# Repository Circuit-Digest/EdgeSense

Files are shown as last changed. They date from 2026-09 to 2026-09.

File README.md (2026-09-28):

# EdgeSense: STM32 Edge AI Texture and Gesture Classifier

```
  ███████╗██████╗  ██████╗ ███████╗███████╗███████╗███╗   ██╗███████╗███████╗
  ██╔════╝██╔══██╗██╔════╝ ██╔════╝██╔════╝██╔════╝████╗  ██║██╔════╝██╔════╝
  █████╗  ██║  ██║██║  ███╗█████╗  ███████╗█████╗  ██╔██╗ ██║███████╗█████╗  
  ██╔══╝  ██║  ██║██║   ██║██╔══╝  ╚════██║██╔══╝  ██║╚██╗██║╚════██║██╔══╝  
  ███████╗██████╔╝╚██████╔╝███████╗███████║███████╗██║ ╚████║███████║███████╗
  ╚══════╝╚═════╝  ╚═════╝ ╚══════╝╚══════╝╚══════╝╚═╝  ╚═══╝╚══════╝╚══════╝
```







**EdgeSense** is a compact, high-performance edge artificial intelligence platform that performs on-device 3D gesture recognition, surface/texture classification, static hand posture detection, and optical obscuration sensing. 

Powered by the **STM32H533CEU6** (ARM Cortex-M33 running at 250 MHz) and the **ST VL53L8CH** 8x8 direct Time-of-Flight (dToF) sensor, EdgeSense executes quantized neural networks entirely on-chip in real time with sub-7 ms inference latency.

---

## Key Capabilities

EdgeSense features a runtime multi-model execution engine (`pipeline_manager.c`) allowing dynamic model switching over USB CDC:

1. **3D Gesture Recognition (8x8 ToF, 15 FPS)**:
   - Recognizes dynamic directional swipes: `SWIPE_LEFT`, `SWIPE_RIGHT`, `SWIPE_UP`, `SWIPE_DOWN`, and `IDLE`.
   - Continuous 15-frame sliding window (1.0 s temporal context) with zero gesture-lockout.
   - Physical temporal motion energy guard to eliminate stationary phantom triggers.
   - Inference latency: **~6.8 ms** per inference.

2. **Distance-Invariant Surface Classifier (4x4 CNH, 48 Bins)**:
   - Classifies textures and materials: `HARD_FLOOR` (tile/wood), `CARPET` (subsurface scattering), `SPECULAR` (mirrors/polished metal), and `VOID` (drop-offs/cliffs).
   - Utilizes ST-aligned Cumulative Normalized Histogram (CNH) peak-centered canonical alignment.
   - Inference latency: **~3.2 ms** per inference.

3. **Static Hand Posture Classifier (8x8 Depth + Signal Intensity)**:
   - Identifies static human hand postures: `FLAT_HAND`, `LIKE`, `DISLIKE`, `BREAK_TIME`, `FIST`, and `NONE`.
   - Dual-channel 2D-CNN processing distance geometry and photon reflection intensity simultaneously.
   - Robust to ambient lighting variations and skin tone differences.
   - Inference latency: **~4.1 ms** per inference.

4. **Optical Obscuration & Smoke Detector**:
   - Detects microscopic particles, airborne obscuration, and smoke.
   - Computes multi-zone signal attenuation and ambient light scattering indices in real time.

---

## Hardware Specifications

| Component | Specification |
|---|---|
| **Microcontroller** | STMicroelectronics STM32H533CEUx (ARM Cortex-M33, 250 MHz, TrustZone, FPU, DSP) |
| **On-Chip Memory** | 512 KB Flash ROM, 256 KB SRAM |
| **ToF Sensor** | STMicroelectronics VL53L8CH / VL53LMZ Direct Time-of-Flight |
| **Sensor FoV** | 65° Diagonal Field of View |
| **Spatial Resolution** | 8x8 (64 zones) or 4x4 (16 zones with 48-bin CNH histograms) |
| **Ranging Distance** | 20 mm to 4000 mm |
| **Host Connectivity** | High-Speed USB 2.0 CDC (Virtual COM Port @ 921600 baud) |
| **Communication Bus** | Dedicated Fast-mode Plus (Fm+) 1 MHz I2C bus |
| **Power Supply** | 5V via USB-C or 3.3V external rail |

---

## Repository Structure

```
EdgeSense/
├── Core/                      # STM32H533 HAL drivers, ISRs, and main loop
├── Drivers/                   # CMSIS and STM32H5xx HAL libraries
├── Middlewares/               # ST X-CUBE-AI runtime v10.2.1 & USB Device stack
├── USB_Device/                # USB CDC Virtual COM Port descriptors & handlers
├── VL53LMZ_ULD/               # Ultra-Lite Driver & CNH Histogram Plugin
├── X-CUBE-AI/                 # Edge AI Pipeline Manager & Active Networks
│   └── App/                   # pipeline_manager, model_gesture, model_posture, model_surface, model_smoke
│
├── Models/                    # Pre-trained production ONNX models & datasets
│   ├── gesture_nn_model.onnx  # 5-class 2D-CNN Gesture Classifier
│   ├── posture_nn_model.onnx  # 6-class 2D-CNN Posture Classifier
│   ├── surface_nn_model.onnx  # 4-class 1D-CNN Surface Classifier
│   ├── gesture_dataset.npz    # Default Gesture training dataset
│   ├── posture_dataset.npz    # Default Posture training dataset
│   ├── surface_dataset.npz    # Default Surface training dataset
│   └── Archive/               # Intermediate training iterations
│
├── Tools/                     # Python Studio, GUIs, and deploy automation
│   ├── Studio/                # 4-in-1 EdgeSense Neural Network Studio
│   │   ├── edgesense_nn_studio.py
│   │   ├── run_nn_studio.bat
│   │   ├── deploy_model_to_mcu.bat
│   │   ├── deploy_posture_model_to_mcu.bat
│   │   ├── deploy_surface_model_to_mcu.bat
│   │   ├── requirements.txt
│   │   └── screenshots/
│   ├── Visualizer/            # Real-time multi-zone depth viewer
│   ├── Flashing/              # STM32CubeProgrammer CLI flasher
│   └── Tests/                 # Automated AT pipeline verification tests
│
├── Hardware/                  # KiCad EDA design files, schematics & BOM
│   ├── Schematics/            # KiCad project, schematics, PCB layout
│   └── Production/            # Gerber ZIP, Pick-and-Place, BOM
│
├── Docs/                      # Technical references & protocol manuals
│   ├── Architecture.md        # System architecture and memory specs
│   └── AT_Command_Manual.md   # Complete AT command serial reference
│
├── EdgeSense.ioc              # STM32CubeMX hardware pinout and clock config
├── STM32H533CEUX_FLASH.ld     # Flash linker script
├── LICENSE                    # GNU General Public License v3.0
└── README.md                  # This documentation
```

---

## Getting Started

### 1. Prerequisites
- **STM32CubeIDE** (v2.2.0 or newer) with GNU Tools for STM32 (ARM GCC 14.3+)
- **ST Edge AI Core (X-CUBE-AI)** v10.2.1+
- **Python** 3.10+ (64-bit)
- **ST-LINK V2 / V3** Programmer

### 2. Python Environment Setup
Install the required dependencies for the EdgeSense AI Studio:
```bash
cd Tools/Studio
pip install -r requirements.txt
```

### 3. Launching EdgeSense Studio
Double-click `Tools/Studio/run_nn_studio.bat` or run:
```bash
python Tools/Studio/edgesense_nn_studio.py
```
From the Studio, you can:
- View live 8x8 depth heatmaps and 4x4 CNH pulse shapes.
- Record new training datasets for Gestures, Postures, or Surfaces.
- Train PyTorch neural networks with 1 click.
- Deploy trained models to the STM32H533 via `deploy_*_model_to_mcu.bat` automatically.

### 4. Building Firmware via Command Line
```bash
make -C Debug all
```
The compiled binary will be located at `Debug/EdgeSense.elf` and `Debug/EdgeSense.bin`.

### 5. Flashing Firmware
Connect your ST-LINK to the SWD header and run:
```bash
Tools/Flashing/flash_firmware.bat
```

---

## Serial Communication & AT Commands

Connect to the USB CDC COM port at **921600 baud, 8-N-1**.

| Command | Action |
|---|---|
| `AT` | Verify connection (returns `OK`) |
| `AT+MODE=?` | List available modes: `(0:GESTURE, 1:SURFACE, 2:POSTURE, 3:SMOKE)` |
| `AT+MODE?` | Query currently active mode |
| `AT+MODE=0` | Switch to 3D Gesture Recognition mode |
| `AT+MODE=1` | Switch to Surface / Texture Classifier mode |
| `AT+MODE=2` | Switch to Hand Posture Classifier mode |
| `AT+MODE=3` | Switch to Optical Smoke / Obscuration mode |
| `AT+STREAM=1` | Enable real-time 8x8 JSON depth streaming |
| `AT+STREAM=0` | Disable streaming |
| `AT+STATUS` | View sensor health, frame counts, and FPS |
| `AT+RESET` | Software system reboot |

---

## License

This project is licensed under the **GNU General Public License v3.0**. See the [LICENSE](LICENSE) file for details.

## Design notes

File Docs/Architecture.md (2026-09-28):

# EdgeSense System Architecture & Hardware Specification

/*
 * Architecture.md
 * System pipeline architecture and technical documentation for EdgeSense
 *
 * Copyright (c) 2026 Dharagesh and Circuit Digest
 * https://github.com/Circuit-Digest/EdgeSense
 * Licensed under GNU General Public License v3.0
 */

`
  ███████╗██████╗  ██████╗ ███████╗███████╗███████╗███╗   ██╗███████╗███████╗
  ██╔════╝██╔══██╗██╔════╝ ██╔════╝██╔════╝██╔════╝████╗  ██║██╔════╝██╔════╝
  █████╗  ██║  ██║██║  ███╗█████╗  ███████╗█████╗  ██╔██╗ ██║███████╗█████╗  
  ██╔══╝  ██║  ██║██║   ██║██╔══╝  ╚════██║██╔══╝  ██║╚██╗██║╚════██║██╔══╝  
  ███████╗██████╔╝╚██████╔╝███████╗███████║███████╗██║ ╚████║███████║███████╗
  ╚══════╝╚═════╝  ╚═════╝ ╚══════╝╚══════╝╚══════╝╚═╝  ╚═══╝╚══════╝╚══════╝
`

---

## 1. Hardware Architecture

EdgeSense is an ultra-compact edge AI sensing node combining:
- **MCU**: STMicroelectronics **STM32H533CEUx**
  - ARM Cortex-M33 with TrustZone, FPU (single-precision), DSP instructions
  - 250 MHz core clock, 512 KB Flash, 256 KB SRAM
  - High-Speed USB 2.0 (FS Device PHY)
  - Dedicated I3C / Fast-mode Plus (Fm+) 1 MHz I2C bus
- **Sensor**: STMicroelectronics **VL53L8CH / VL53LMZ** Direct Time-of-Flight (dToF)
  - 8x8 multizone ranging (64 independent distance zones)
  - 4x4 Cumulative Normalized Histogram (CNH) binning mode (48 physical bins per zone)
  - 940 nm VCSEL emitter with integrated metasurface lens
  - Wide 65° diagonal Field of View (FoV)

---

## 2. Firmware Execution Pipeline

EdgeSense runs an interrupt-driven, bare-metal cooperative architecture designed for low latency and zero heap fragmentation:

`mermaid
graph TD
    A[VL53LMZ Hardware INT Pin] -->|EXTI Fallback / Poll| B[Ranging Data Ready]
    B --> C[vl53lmz_get_ranging_data]
    C --> D{Active Pipeline Mode}
    D -->|MODE_GESTURE| E[model_gesture_process]
    D -->|MODE_SURFACE| F[model_surface_process]
    D -->|MODE_POSTURE| G[model_posture_process]
    D -->|MODE_SMOKE| H[model_smoke_process]
    E --> I[pipeline_manager_report_event]
    F --> I
    G --> I
    H --> I
    I -->|JSON / ASCII| J[USB CDC Virtual COM Port]
`

### Memory Footprint on STM32H533CEUx
- **Flash ROM**: ~230 KB (45% of 512 KB)
- **SRAM**: ~87 KB (34% of 256 KB)
- **Network Weights & Activations**:
  - gesture_nn: 18.5 KB weights, 15.0 KB activations buffer (reusable pool)
  - posture_nn: 12.2 KB weights, 8.4 KB activations buffer
  - surface_nn: 7.8 KB weights, 4.2 KB activations buffer

---

## 3. Dynamic Mode Switching Engine

The runtime switching engine (pipeline_manager.c) controls sensor configuration and active neural network instances without resetting the MCU:

1. Sensor ranging is safely stopped via 
l53lmz_stop_ranging().
2. Sensor resolution is re-indexed:
   - **Gesture / Posture / Smoke**: VL53LMZ_RESOLUTION_8X8 (64 zones, 15 Hz)
   - **Surface Classification**: VL53LMZ_RESOLUTION_4X4 with CNH histogram readout
3. The AI network pointer is dynamically swapped in the pipeline table.
4. Feature buffers are zeroed to prevent cross-mode bleed.
5. Ranging is restarted via 
l53lmz_start_ranging().

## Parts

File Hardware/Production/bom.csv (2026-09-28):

Designator | Footprint | Quantity | Value | LCSC Part #
C1, C20, C3, C4, C5, C6 | 0603 | 6 | 1uF
C12, C13, C14, C15, C16, C27, C28, C29, C30 | 0603 | 9 | 100nF
C17 | 0603 | 1 | 10uF
C18, C19 | 0603 | 2 | 2.2uF
C2 | 0603 | 1 | 10nF
C21, C22 | 0603 | 2 | 0.1uF
C23, C24 | 0603 | 2 | 18pF
C25, C26 | 0603 | 2 | 9pF
D1, D2 | 0603 | 2 | LED
IC1 | UFQFPN-48_STM | 1 | STM32H533CEU6
IC2 | VL53L8CHV0GC1 | 1 | VL53L8CHV0GC_1
J2 | JST_PH_B2B-PH-K_1x02_P2.00mm_Vertical | 1 | BAT
J3 | PinHeader_1x05_P2.54mm_Vertical | 1 | STLINK
J4 | USB_C_Receptacle_HCTL_HC-TYPE-C-16P-01A | 1 | USB_C_Receptacle_USB2.0_16P
J5 | PinHeader_1x04_P2.54mm_Vertical | 1 | UART
R1 | 0603 | 1 | 12K
R10, R14, R15, R16, R8, R9 | 0603 | 6 | 47K
R11, R6 | 0603 | 2 | 10K
R12, R13 | 0603 | 2 | 5K1
R17 | 0603 | 1 | 7K5
R2 | 0603 | 1 | 3K3
R3 | 0603 | 1 | 1K
R4 | 0603 | 1 | 470R
R5, R7 | 0603 | 2 | 220R
SW1, SW2 | SW_SPST_TS-1088-xR025 | 2 | SW_Push
U1 | DFN_SPU33R_STM | 1 | ST1L08SPU33R
U2 | VFQFPN-16_STM | 1 | L6924D013TR
U3 | SOT-223-3_TabPin2 | 1 | LD1117V18
U4 | TSSOP20_4P4X6P5_STM | 1 | ST2378ETTR
Y1 | Crystal_SMD_3215-2Pin_3.2x1.5mm | 1 | 32KHz
Y2 | Crystal_SMD_3225-4Pin_3.2x2.5mm | 1 | Crystal_GND24_Small

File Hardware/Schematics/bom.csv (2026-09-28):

Designator | Footprint | Quantity | Manufacturer part number | LCSC Part #
BAT | JST_PH_B2B-PH-K_1x02_P2.00mm_Vertical | 1 | BAT
C1, C20, C3, C4, C5, C6 | 603 | 6 | 1uF
C10, C12, C13, C14, C15, C16, C8, C9 | 603 | 8 | 100nF
C17, C23, C24 | 603 | 3 | 10uF
C18, C19 | 603 | 2 | 2.2uF
C2 | 603 | 1 | 10nF
C21, C22 | 603 | 2 | 0.1uF
C25, C26 | 603 | 2 | 9pF
D1, D2 | 603 | 2 | LED
IC1 | UFQFPN-48_STM | 1 | STM32H533CEU6
IC2 | VL53L8CHV0GC1 | 1 | VL53L8CHV0GC_1
J3 | PinHeader_1x05_P2.54mm_Vertical | 1 | STLINK
J4 | USB_C_Receptacle_HCTL_HC-TYPE-C-16P-01A | 1 | USB_C_Receptacle_USB2.0_16P
J5 | PinHeader_1x04_P2.54mm_Vertical | 1 | UART
R1 | 603 | 1 | 12K
R10, R14, R15, R16, R8, R9 | 603 | 6 | 47K
R11, R6 | 603 | 2 | 10K
R12, R13 | 603 | 2 | 5K1
R17_2 | 603 | 1 | 7K5
R17 | 603 | 1 | 7500R
R2 | 603 | 1 | 3K3
R3 | 603 | 1 | 1K
R4 | 603 | 1 | 470R
R5, R7 | 603 | 2 | 220R
SW1, SW2 | SW_SPST_TS-1088-xR025 | 2 | SW_Push
U1 | DFN_SPU33R_STM | 1 | ST1L08SPU33R
U2 | VFQFPN-16_STM | 1 | L6924D013TR
U3 | SOT-223-3_TabPin2 | 1 | LD1117V18
U4 | TSSOP20_4P4X6P5_STM | 1 | ST2378ETTR
Y1 | Crystal_SMD_3215-2Pin_3.2x1.5mm | 1 | 32KHz
Y2 | XTAL_ABM8-24.000MHZ-D2Y-T | 1 | 24MHz

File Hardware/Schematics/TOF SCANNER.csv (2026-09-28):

Id | Designator | Footprint | Quantity | Designation | Supplier and ref
1 | BAT | JST_PH_B2B-PH-K_1x02_P2.00mm_Vertical | 1 | BAT
2 | C1, C3, C4, C5, C6, C20 | C_0603_1608Metric | 6 | 1uF
3 | C2 | C_0603_1608Metric | 1 | 10nF
4 | C8, C9, C10, C12, C13, C14, C15, C16 | C_0603_1608Metric | 8 | 100nF
5 | C17, C23, C24 | C_0603_1608Metric | 3 | 10uF
6 | C18, C19 | C_0603_1608Metric | 2 | 2.2uF
7 | C21, C22 | C_0603_1608Metric | 2 | 0.1uF
8 | C25, C26 | C_0603_1608Metric | 2 | 9pF
9 | D1, D2 | LED_0603_1608Metric | 2 | LED
10 | IC1 | UFQFPN-48_STM | 1 | STM32H533CEU6
11 | IC2 | VL53L8CHV0GC1 | 1 | VL53L8CHV0GC_1
12 | J3 | PinHeader_1x05_P2.54mm_Vertical | 1 | STLINK
13 | J4 | USB_C_Receptacle_HCTL_HC-TYPE-C-16P-01A | 1 | USB_C_Receptacle_USB2.0_16P
14 | J5 | PinHeader_1x04_P2.54mm_Vertical | 1 | UART
15 | R1 | R_0603_1608Metric | 1 | 12K
16 | R2 | R_0603_1608Metric | 1 | 3K3
17 | R3 | R_0603_1608Metric | 1 | 1K
18 | R4 | R_0603_1608Metric | 1 | 470R
19 | R5, R7 | R_0603_1608Metric | 2 | 220R
20 | R6, R11 | R_0603_1608Metric | 2 | 10K
21 | R8, R9, R10, R14, R15, R16 | R_0603_1608Metric | 6 | 47K
22 | R12, R13 | R_0603_1608Metric | 2 | 5K1
23 | R17 | R_0603_1608Metric | 1 | 7K5
24 | R17 | R_0603_1608Metric | 1 | 7500R
25 | SW1, SW2 | SW_SPST_TS-1088-xR025 | 2 | SW_Push
26 | U1 | DFN_SPU33R_STM | 1 | ST1L08SPU33R
27 | U2 | VFQFPN-16_STM | 1 | L6924D013TR
28 | U3 | SOT-223-3_TabPin2 | 1 | LD1117V18
29 | U4 | TSSOP20_4P4X6P5_STM | 1 | ST2378ETTR
30 | Y1 | Crystal_SMD_3215-2Pin_3.2x1.5mm | 1 | 32KHz
31 | Y2 | XTAL_ABM8-24.000MHZ-D2Y-T | 1 | 24MHz

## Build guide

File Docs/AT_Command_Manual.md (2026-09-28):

# EdgeSense AT Command Interface Manual

/*
 * AT_Command_Manual.md
 * Serial Command Protocol and Pipeline Control Specification
 *
 * Copyright (c) 2026 Dharagesh and Circuit Digest
 * https://github.com/Circuit-Digest/EdgeSense
 * Licensed under GNU General Public License v3.0
 */

All commands are sent over the USB CDC Virtual COM port (921600 baud, 8-N-1) terminated with \r\n (CRLF).

---

## Command Reference

| Command | Parameter | Response | Description |
|---|---|---|---|
| `AT` | *None* | `OK` | Link verification / Ping |
| `AT+MODE=?` | *None* | `+MODE: (0:GESTURE, 1:SURFACE, 2:POSTURE, 3:SMOKE)` | List supported operating modes |
| `AT+MODE?` | *None* | `+MODE: <id>,<NAME>` | Query current operating mode |
| `AT+MODE=<id>` | `0` to `3` | `OK` or `ERROR: ...` | Switch active pipeline mode at runtime |
| `AT+STREAM=<en>` | `0` or `1` | `OK` | Enable (`1`) or disable (`0`) real-time JSON depth matrix streaming |
| `AT+STATUS` | *None* | Multi-line diagnostic dump | Get sensor health, frame count, temperature, and FPS |
| `AT+INFO` | *None* | Firmware metadata | Print version, MCU target, sensor UID, and build date |
| `AT+RESET` | *None* | `OK` | Perform software system reset via NVIC |

---

## Operating Modes

### Mode 0: 3D Gesture Recognition (`GESTURE`)
- **Resolution**: 8x8 zones (64 zones) @ 15 Hz
- **Architecture**: 2D-CNN with 15-frame sliding window (1.0 s temporal history)
- **Output Classes**: `IDLE`, `SWIPE_LEFT`, `SWIPE_RIGHT`, `SWIPE_UP`, `SWIPE_DOWN`
- **Output Event**:
  `[AI GESTURE] >>> DETECTED: SWIPE_LEFT (Confidence:  96.7% | Latency: 6805 us | 1633263 cycles) <<<`

### Mode 1: Surface / Texture Classifier (`SURFACE`)
- **Resolution**: 4x4 zones (16 zones) with 48-bin CNH histograms @ 15 Hz
- **Architecture**: 1D-CNN Canonical Peak-Centered Histogram Network
- **Output Classes**: `HARD_FLOOR`, `CARPET`, `SPECULAR`, `VOID`
- **Output Event**:
  `[AI SURFACE] >>> DETECTED: CARPET (Confidence:  98.2% | Latency: 3210 us) <<<`

### Mode 2: Static Hand Posture Classifier (`POSTURE`)
- **Resolution**: 8x8 zones (64 zones) @ 15 Hz
- **Architecture**: Dual-Channel 2D-CNN (Depth + Signal Intensity)
- **Output Classes**: `NONE`, `FLAT_HAND`, `LIKE`, `DISLIKE`, `BREAK_TIME`, `FIST`
- **Output Event**:
  `[AI POSTURE] >>> DETECTED: LIKE (Confidence:  97.5% | Latency: 4120 us) <<<`

### Mode 3: Optical Obscuration / Smoke Detector (`SMOKE`)
- **Resolution**: 8x8 zones (64 zones) @ 15 Hz
- **Methodology**: Multi-zone signal attenuation and ambient light scattering ratio
- **Output Event**:
  `[AI SMOKE] >>> ALERT: OBSCURATION_DETECTED (Level: 42% | Attenuation: -3.8 dB) <<<`

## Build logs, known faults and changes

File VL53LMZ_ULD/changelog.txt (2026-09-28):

********************************************************************************
*
* STMicroelectronics - VL53L7CH/VL53L8CH Ultra Lite Driver
*
********************************************************************************

# Driver version history 

---------------------------------------------------------------------------------------------------------------
Version : 2.0.16
Date: 24/06/2025
Comments :
- Add missing declarations for vl53lmz_get_ranging_frequency_x256() / vl53lmz_set_ranging_frequency_x256()
- Modified glare_filter get/set functions to not generate compiler warnings.
- Skipped version 2.0.15 due to confusion about update history.
---------------------------------------------------------------------------------------------------------------

---------------------------------------------------------------------------------------------------------------
Version : 2.0.14
Date: 14/11/2024
Comments :
- Fix compatibility with VL53L7.
- New API functions to allow more precise setting of ranging frequency:
  -- vl53lmz_get_ranging_frequency_x256() / vl53lmz_set_ranging_frequency_x256()
---------------------------------------------------------------------------------------------------------------

---------------------------------------------------------------------------------------------------------------
Version : 2.0.13
Date: 12/11/2024
Comments :
- Updates in vl53lmz_buffers.h file to align it with L8CX ULD v2.0.0 (updated spread spectrum settings)
- Enable download FW checksum feature.
- Added SPI example project. Aligned I2C and SPI projects.
- Added GPIO pin allocation PDF files in example projects.
---------------------------------------------------------------------------------------------------------------

---------------------------------------------------------------------------------------------------------------
Version : 2.0.11
Date: 12/03/2024
Comments :
- Changed method used to set module_type so that it correctly distinguishes between L5 and L7 parts.
- Modified vl53lmz_is_alive() to only store device_id and revision_id.
- Moved to MM FW v1.8 (modified field order in low_reflectance_filter_t)
---------------------------------------------------------------------------------------------------------------

---------------------------------------------------------------------------------------------------------------
Version : 2.0.10
Date: 07/12/2023
Comments :
- Fixed wrong conversion of Ambient and Histogram values in Example_12. Values were a factor of 2x too low.
- Fixed incorrect sizing of cnh_data_buffer_t.
- Fixed incorrect comparison for is_auto_stop_enabled.
- Added VL53LMZ_POWER_MODE_DEEP_SLEEP mode.
- Include MM FW v1.7 which contains:
.... Improved rad2perp for L8
.... Improved wrap-around check algo
.... Option to skip intr on first two frames of detection thresholds
.... Calculation of a FW checksum
.... Fix for incorrect operation with very negative values of CNH start_bin
.... Added first_bin to sci_persistent_data[2][31:16]
---------------------------------------------------------------------------------------------------------------

---------------------------------------------------------------------------------------------------------------
Version : 2.0.9
Date : 25/07/2023
Comments :
- Fixed issue in  vl53lmz_enable/disable_internal_cp functions which prevented use with VL53L7CH.
- Added module_type to VL53LMZ_Configuration to provide a public location to read the module type. This
field is set during calls to vl53lmz_is_alive() and vl53lmz_init().
---------------------------------------------------------------------------------------------------------------

---------------------------------------------------------------------------------------------------------------
Version : 2.0.8
Date : 16/06/2023
Comments : Initial driver release.
---------------------------------------------------------------------------------------------------------------

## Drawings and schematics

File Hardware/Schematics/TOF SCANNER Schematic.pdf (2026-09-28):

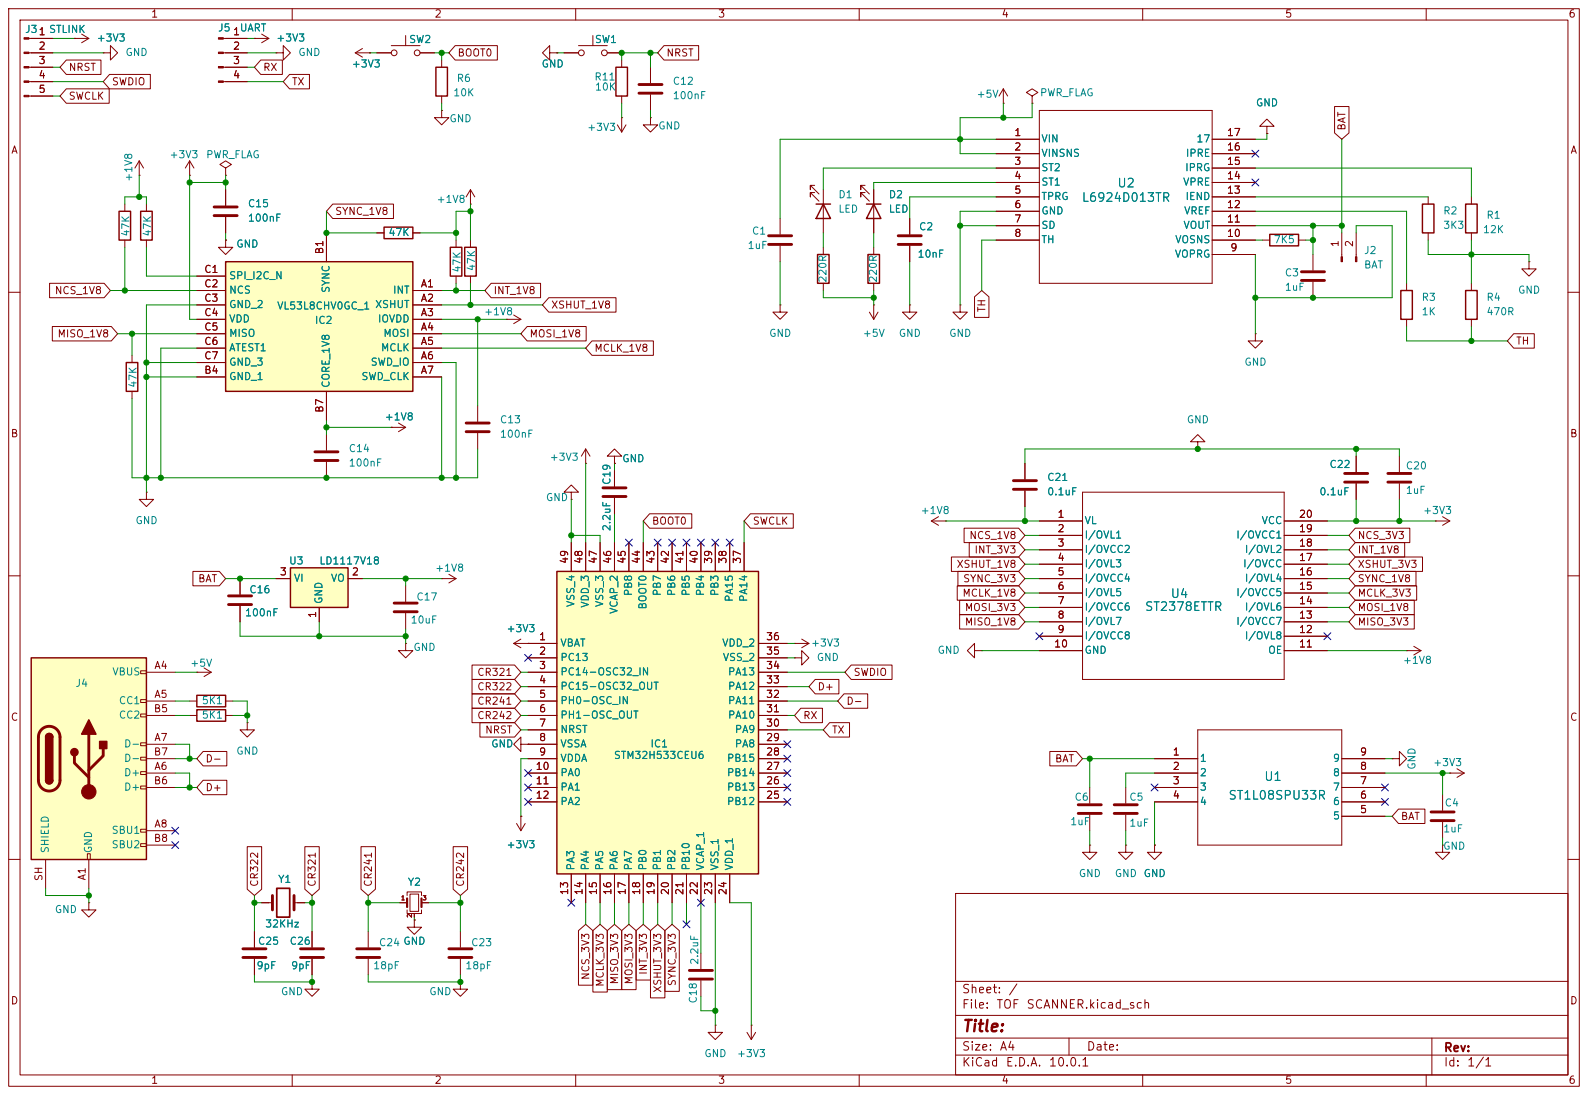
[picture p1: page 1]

VDD C4 MISO C5

ATEST1 C6 GND_3 C7

Size: A4 | Rev:
KiCad E.D.A. 10.0.1 | Id: 1/1

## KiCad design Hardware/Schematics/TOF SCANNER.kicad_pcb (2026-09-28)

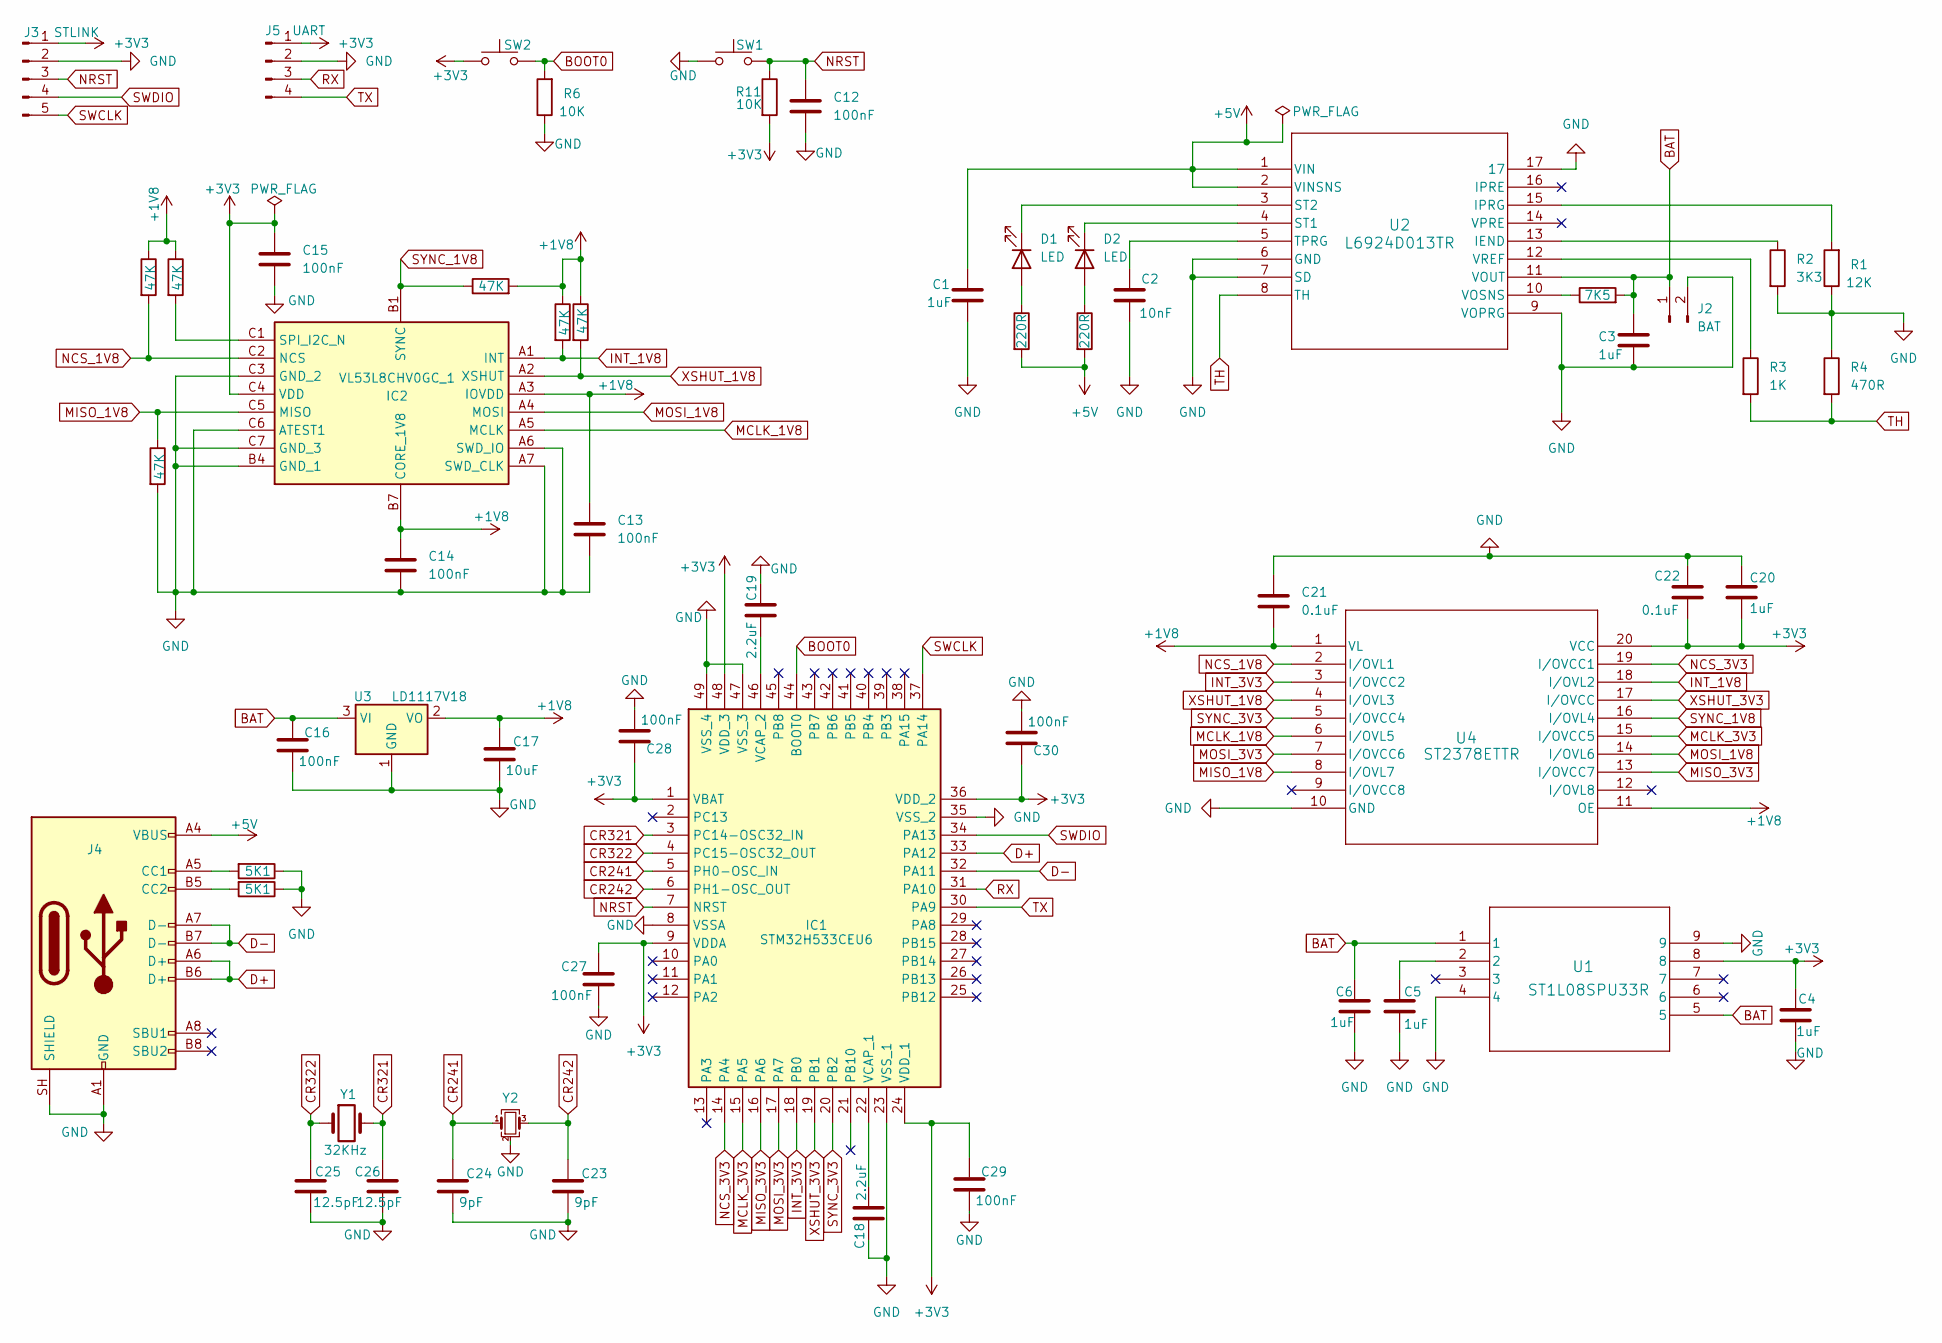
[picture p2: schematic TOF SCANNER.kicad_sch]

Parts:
C1, C3, C4, C5, C6, C20: 1uF; C_0603_1608Metric
C2: 10nF; C_0603_1608Metric
C12, C13, C14, C15, C16, C27, C28, C29, C30: 100nF; C_0603_1608Metric
C17: 10uF; C_0603_1608Metric
C18, C19: 2.2uF; C_0603_1608Metric
C21, C22: 0.1uF; C_0603_1608Metric
C23, C24: 9pF; C_0603_1608Metric
C25, C26: 12.5pF; C_0603_1608Metric
D1, D2: LED; LED_0603_1608Metric
IC1: STM32H533CEU6; UFQFPN-48_STM; Mouser Part Number 511-STM32H533CEU6
IC2: VL53L8CHV0GC_1; VL53L8CHV0GC1; Mouser Part Number 511-VL53L8CHV0GC/1
J2: BAT; JST_PH_B2B-PH-K_1x02_P2.00mm_Vertical
J3: STLINK; PinHeader_1x05_P2.54mm_Vertical
J4: USB_C_Receptacle_USB2.0_16P; USB_C_Receptacle_HCTL_HC-TYPE-C-16P-01A
J5: UART; PinHeader_1x04_P2.54mm_Vertical
R1: 12K; R_0603_1608Metric
R2: 3K3; R_0603_1608Metric
R3: 1K; R_0603_1608Metric
R4: 470R; R_0603_1608Metric
R5, R7: 220R; R_0603_1608Metric
R6, R11: 10K; R_0603_1608Metric
R8, R9, R10, R14, R15, R16: 47K; R_0603_1608Metric
R12, R13: 5K1; R_0603_1608Metric
R17: 7K5; R_0603_1608Metric
SW1, SW2: SW_Push; SW_SPST_TS-1088-xR025
U1: ST1L08SPU33R; DFN_SPU33R_STM
U2: L6924D013TR; VFQFPN-16_STM
U3: LD1117V18; SOT-223-3_TabPin2
U4: ST2378ETTR; TSSOP20_4P4X6P5_STM
Y1: 32KHz; Crystal_SMD_3215-2Pin_3.2x1.5mm
Y2: Crystal_GND24_Small; Crystal_SMD_3225-4Pin_3.2x2.5mm

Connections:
+1V8: C13.1, C14.1, C17.1, C21.2, IC2.A3 (IOVDD), IC2.B7 (CORE_1V8), R8.1, R9.2, R10.1, R14.1, R15.1, U3.2 (VO), U4.1 (VL), U4.11 (OE)
+3V3: C4.1, C15.1, C20.2, C22.2, C27.1, C28.1, C29.1, C30.1, IC1.1 (VBAT), IC1.9 (VDDA), IC1.24 (VDD_1), IC1.36 (VDD_2), IC1.48 (VDD_3), IC2.C4 (VDD), J3.1, J5.1, R11.2, SW2.1, U1.8, U4.20 (VCC)
+5V: C1.1, J4.A4 (VBUS), J4.A9 (VBUS), J4.B4 (VBUS), J4.B9 (VBUS), R5.2, R7.2, U2.1 (VIN), U2.2 (VINSNS)
BAT: C3.1, C6.1, C16.1, J2.1, R17.2, U1.1, U1.5, U2.11 (VOUT), U3.3 (VI)
BOOT0: IC1.44 (BOOT0), R6.2, SW2.2
CR241: C24.1, IC1.5 (PH0-OSC_IN), Y2.1
CR242: C23.1, IC1.6 (PH1-OSC_OUT), Y2.3
CR321: C26.1, IC1.3 (PC14-OSC32_IN), Y1.2
CR322: C25.1, IC1.4 (PC15-OSC32_OUT), Y1.1
D+: IC1.33 (PA12), J4.A6 (D+), J4.B6 (D+)
D-: IC1.32 (PA11), J4.A7 (D-), J4.B7 (D-)
GND: C1.2, C2.2, C3.2, C4.2, C5.2, C6.2, C12.2, C13.2, C14.2, C15.2, C16.2, C17.2, C18.1, C19.2, C20.1, C21.1, C22.1, C23.2, C24.2, C25.2, C26.2, C27.2, C28.2, C29.2, C30.2, IC1.8 (VSSA), IC1.23 (VSS_1), IC1.35 (VSS_2), IC1.47 (VSS_3), IC1.49 (VSS_4), IC2.A6 (SWD_IO), IC2.A7 (SWD_CLK), IC2.B4 (GND_1), IC2.C3 (GND_2), IC2.C6 (ATEST1), IC2.C7 (GND_3), J2.2, J3.2, J4.A1 (GND), J4.A12 (GND), J4.B1 (GND), J4.B12 (GND), J4.SH (SHIELD), J5.2, R1.1, R2.2, R4.1, R6.1, R12.1, R13.1, R16.2, SW1.1, U1.4, U1.9, U2.6 (GND), U2.7 (SD), U2.9 (VOPRG), U2.17, U3.1 (GND), U4.10 (GND), Y2.2 (G), Y2.4 (G)
INT_1V8: IC2.A1 (INT), R8.2, U4.18 (I/OVL2)
INT_3V3: IC1.18 (PB0), U4.3 (I/OVCC2)
MCLK_1V8: IC2.A5 (MCLK), U4.6 (I/OVL5)
MCLK_3V3: IC1.15 (PA5), U4.15 (I/OVCC5)
MISO_1V8: IC2.C5 (MISO), R16.1, U4.8 (I/OVL7)
MISO_3V3: IC1.16 (PA6), U4.13 (I/OVCC7)
MOSI_1V8: IC2.A4 (MOSI), U4.14 (I/OVL6)
MOSI_3V3: IC1.17 (PA7), U4.7 (I/OVCC6)
NCS_1V8: IC2.C2 (NCS), R15.2, U4.2 (I/OVL1)
NCS_3V3: IC1.14 (PA4), U4.19 (I/OVCC1)
NRST: C12.1, IC1.7 (NRST), J3.3, R11.1, SW1.2
unnamed: C5.1, U1.2
unnamed: D1.2 (A), R7.1
unnamed: D1.1 (K), U2.3 (ST2)
unnamed: D2.2 (A), R5.1
unnamed: D2.1 (K), U2.4 (ST1)
unnamed: C18.2, IC1.22 (VCAP_1)
unnamed: C19.1, IC1.46 (VCAP_2)
unnamed: IC2.C1 (SPI_I2C_N), R14.2
unnamed: J4.A5 (CC1), R12.2
unnamed: J4.B5 (CC2), R13.2
unnamed: R2.1, U2.13 (IEND)
unnamed: R1.2, U2.15 (IPRG)
unnamed: C2.1, U2.5 (TPRG)
unnamed: R17.1, U2.10 (VOSNS)
unnamed: R3.1, U2.12 (VREF)
RX: IC1.31 (PA10), J5.3
SWCLK: IC1.37 (PA14), J3.5
SWDIO: IC1.34 (PA13), J3.4
SYNC_1V8: IC2.B1 (SYNC), R9.1, U4.16 (I/OVL4)
SYNC_3V3: IC1.20 (PB2), U4.5 (I/OVCC4)
TH: R3.2, R4.2, U2.8 (TH)
TX: IC1.30 (PA9), J5.4
XSHUT_1V8: IC2.A2 (XSHUT), R10.2, U4.4 (I/OVL3)
XSHUT_3V3: IC1.19 (PB1), U4.17 (I/OVCC)

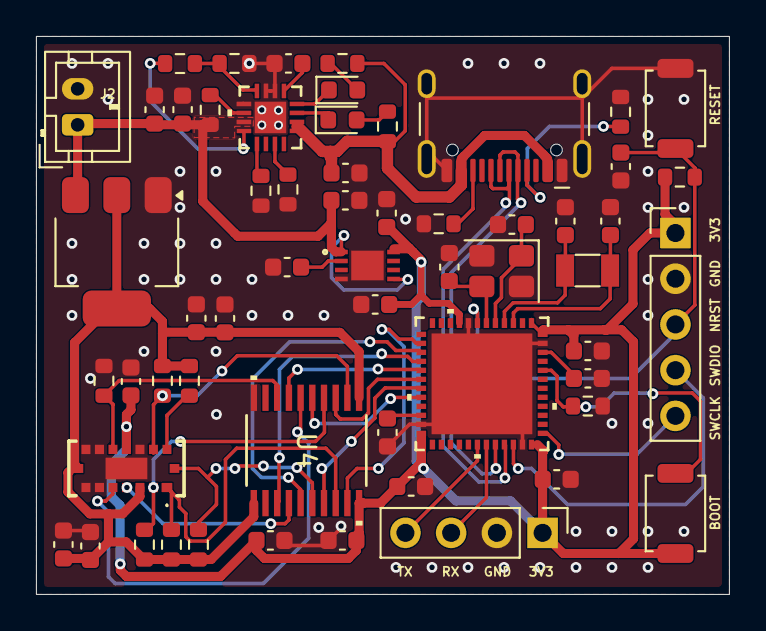
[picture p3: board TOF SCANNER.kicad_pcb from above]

Board: 2 copper layers, 38.5 x 31.0 mm, 58 parts (0 on the bottom side), 47 nets.

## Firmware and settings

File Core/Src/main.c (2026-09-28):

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
/* Includes ------------------------------------------------------------------*/
#include "main.h"
#include "usb_device.h"
#include "app_x-cube-ai.h"

/* USER CODE BEGIN Includes */
#include <stdio.h>
#include <string.h>
#include "usbd_cdc_if.h"
#include "vl53lmz_api.h"
#include "vl53lmz_plugin_cnh.h"
#include "platform.h"
#include "at_cmd.h"
#include "pipeline_manager.h"
/* USER CODE END Includes */


SPI_HandleTypeDef hspi1;

UART_HandleTypeDef huart1;

PCD_HandleTypeDef hpcd_USB_DRD_FS;

/* USER CODE BEGIN PV */
extern volatile uint32_t g_usb_irq_count;

static VL53LMZ_Configuration         g_vl53lmz_dev;
static VL53LMZ_ResultsData           g_vl53lmz_results;
static VL53LMZ_Motion_Configuration  g_cnh_config;
static cnh_data_buffer_t             g_cnh_data_buffer;
static uint32_t                      g_cnh_data_size = 0;
static int16_t                       g_cnh_min_dist = 0;
static int16_t                       g_cnh_max_dist = 0;
static uint8_t  g_sensor_initialized = 0;
uint8_t         g_ranging_active     = 0;
static uint32_t g_frame_count        = 0;
static uint32_t g_last_frame_tick    = 0;
float           g_fps                = 0.0f;
static char     s_json_buf[6144];
static uint8_t  g_current_resolution = 64;
static uint16_t g_cnh_num_bins        = 16;
static uint8_t  g_cnh_sub_sample      = 4;
static uint8_t  g_ranging_freq_hz     = 15;
/* USER CODE END PV */

void SystemClock_Config(void);
void PeriphCommonClock_Config(void);
static void MPU_Config(void);
static void MX_GPIO_Init(void);
static void MX_ICACHE_Init(void);
static void MX_SPI1_Init(void);
static void MX_USART1_UART_Init(void);
/* USER CODE BEGIN PFP */
void MX_USB_PCD_Init(void);
/* USER CODE END PFP */

/* USER CODE BEGIN 0 */
// Redirect printf to USB Type-C Virtual COM Port (Non-blocking high-speed)
int __io_putchar(int ch) {
    uint8_t c = (uint8_t)ch;
    CDC_Transmit_FS(&c, 1);
    return ch;
}

// Low-level SPI write for VL53L8CH
void VL_WriteByte(uint16_t reg, uint8_t data) {
    uint8_t tx[3];
    // In VL53L8CH SPI: write bit (bit 15) is 1
    tx[0] = (uint8_t)((reg >> 8) | 0x80);
    tx[1] = (uint8_t)(reg & 0xFF);
    tx[2] = data;

    HAL_GPIO_WritePin(VL_NCS_GPIO_Port, VL_NCS_Pin, GPIO_PIN_RESET); // Chip Select LOW
    HAL_SPI_Transmit(&hspi1, tx, 3, 100);
    HAL_GPIO_WritePin(VL_NCS_GPIO_Port, VL_NCS_Pin, GPIO_PIN_SET);   // Chip Select HIGH
}

// Low-level SPI read for VL53L8CH
uint8_t VL_ReadByte(uint16_t reg) {
    uint8_t tx[2];
    uint8_t rx = 0;
    // In VL53L8CH SPI: read bit (bit 15) is 0
    tx[0] = (uint8_t)((reg >> 8) & 0x7F);
    tx[1] = (uint8_t)(reg & 0xFF);

    HAL_GPIO_WritePin(VL_NCS_GPIO_Port, VL_NCS_Pin, GPIO_PIN_RESET); // Chip Select LOW
    HAL_SPI_Transmit(&hspi1, tx, 2, 100);                             // Send 16-bit address
    HAL_SPI_Receive(&hspi1, &rx, 1, 100);                             // Read byte
    HAL_GPIO_WritePin(VL_NCS_GPIO_Port, VL_NCS_Pin, GPIO_PIN_SET);   // Chip Select HIGH
    return rx;
}



// Ultra-fast integer-to-string append (avoids printf overhead)
static inline char* append_int(char *p, int val) {
    if (val < 0) {
        *p++ = '-';
        val = -val;
    }
    char tmp[10];
    int i = 0;
    do {
        tmp[i++] = (char)('0' + (val % 10));
        val /= 10;
    } while (val > 0);
    while (i > 0) {
        *p++ = tmp[--i];
    }
    return p;
}

// Ultra-fast 1-decimal-place float append (e.g. 12.3)
static inline char* append_fixed1(char *p, float val) {
    if (val < 0.0f) {
        *p++ = '-';
        val = -val;
    }
    uint32_t vi = (uint32_t)val;
    uint32_t vf = (uint32_t)((val - (float)vi) * 10.0f + 0.5f);
    if (vf >= 10) {
        vi++;
        vf = 0;
    }
    char tmp[10];
    int i = 0;
    do {
        tmp[i++] = (char)('0' + (vi % 10));
        vi /= 10;
    } while (vi > 0);
    while (i > 0) {
        *p++ = tmp[--i];
    }
    *p++ = '.';
    *p++ = (char)('0' + vf);
    return p;
}

uint8_t Get_Sensor_Resolution(void) { return g_current_resolution; }
uint16_t Get_Sensor_NumBins(void) { return g_cnh_num_bins; }
uint8_t Get_Sensor_SubSample(void) { return g_cnh_sub_sample; }
uint8_t Get_Sensor_Frequency(void) { return g_ranging_freq_hz; }
void* Get_CNH_Configuration(void) { return (void*)&g_cnh_config; }

/// High-Speed Atomic JSON Packet Streaming (Dynamic Resolution & Bins)
static void Print_JSON_Stream(VL53LMZ_ResultsData *p_res, uint32_t frame_no) {
    char *p = s_json_buf;
    uint8_t num_zones = g_current_resolution;
    uint16_t nb_bins = g_cnh_num_bins;

    // 1. Frame metadata
    *p++ = '{';
    *p++ = '"'; *p++ = 'f'; *p++ = '"'; *p++ = ':';
    p = append_int(p, (int)frame_no);
    *p++ = ',';
    *p++ = '"'; *p++ = 't'; *p++ = '"'; *p++ = ':';
    p = append_int(p, (int)p_res->silicon_temp_degc);
    *p++ = ',';
    *p++ = '"'; *p++ = 'r'; *p++ = 'e'; *p++ = 's'; *p++ = '"'; *p++ = ':';
    p = append_int(p, (int)num_zones);
    *p++ = ',';
    *p++ = '"'; *p++ = 'b'; *p++ = 'i'; *p++ = 'n'; *p++ = 's'; *p++ = '"'; *p++ = ':';
    p = append_int(p, (int)nb_bins);

    // 2. Distance values (16 or 64)
    *p++ = ',';
    *p++ = '"'; *p++ = 'd'; *p++ = '"'; *p++ = ':'; *p++ = '[';
    for (int i = 0; i < num_zones; i++) {
        if (i > 0) *p++ = ',';
        uint8_t status = p_res->target_status[i];
        int16_t d = (status == 5 || status == 6 || status == 9 || status == 4) ? p_res->distance_mm[i] : -1;
        p = append_int(p, (int)d);
    }
    *p++ = ']';

    // 3. Peak Signal values (kcps/SPAD)
    *p++ = ',';
    *p++ = '"'; *p++ = 's'; *p++ = '"'; *p++ = ':'; *p++ = '[';
    for (int i = 0; i < num_zones; i++) {
        if (i > 0) *p++ = ',';
        uint32_t sig = p_res->signal_per_spad[i];
        p = append_int(p, (int)sig);
    }
    *p++ = ']';

    // 4. Native Ambient Noise values (kcps/spad)
    *p++ = ',';
    *p++ = '"'; *p++ = 'a'; *p++ = '"'; *p++ = ':'; *p++ = '[';
    for (int i = 0; i < num_zones; i++) {
        if (i > 0) *p++ = ',';
        p = append_int(p, (int)p_res->ambient_per_spad[i]);
    }
    *p++ = ']';

    // 4. Zone Histograms Concurrent Matrix
    *p++ = ',';
    *p++ = '"'; *p++ = 'h'; *p++ = '"'; *p++ = ':'; *p++ = '[';
    for (int z = 0; z < num_zones; z++) {
        if (z > 0) *p++ = ',';
        *p++ = '[';

        int32_t *p_hist = NULL;
        int8_t *p_hist_scaler = NULL;
        int32_t *p_ambient = NULL;
        int8_t *p_ambient_scaler = NULL;

        vl53lmz_cnh_get_block_addresses(&g_cnh_config, z, g_cnh_data_buffer,
                                        &p_hist, &p_hist_scaler, &p_ambient, &p_ambient_scaler);

        if (p_hist && p_hist_scaler) {
            for (int b = 0; b < nb_bins; b++) {
                if (b > 0) *p++ = ',';
                float val = ((float)p_hist[b]) / (float)(1 << p_hist_scaler[b]);
                p = append_fixed1(p, val);
            }
        } else {
            for (int b = 0; b < nb_bins; b++) {
                if (b > 0) *p++ = ',';
                *p++ = '0';
            }
        }
        *p++ = ']';
    }
    *p++ = ']';
    *p++ = '}';
    *p++ = '\r';
    *p++ = '\n';
    *p = '\0';

    int len = p - s_json_buf;

    // Single Atomic Non-blocking USB CDC Transmit
    if (len > 0 && len < (int)sizeof(s_json_buf)) {
        CDC_Transmit_FS((uint8_t*)s_json_buf, (uint16_t)len);
    }
}

uint8_t Init_VL53LMZ_Sensor(void);

uint8_t Set_Sensor_Profile(uint8_t resolution, uint16_t num_bins, uint8_t frequency_hz, uint8_t sub_sample) {
    if (!g_sensor_initialized) {
        return VL53LMZ_STATUS_ERROR;
    }
    if (resolution != 16 && resolution != 64) {
        return VL53LMZ_STATUS_INVALID_PARAM;
    }

    uint8_t status = VL53LMZ_STATUS_OK;
    uint8_t was_ranging = g_ranging_active;

    printf("\r\n[PROFILE] Reconfiguring sensor to %s (%d Zones, %d Bins, SubSample %d @ %d Hz)...\r\n",
           (resolution == 16) ? "4x4" : "8x8", resolution, num_bins, sub_sample, frequency_hz);

    // 1. Stop sensor ranging if active
    if (g_ranging_active) {
        status = vl53lmz_stop_ranging(&g_vl53lmz_dev);
        g_ranging_active = 0;
        if (status != VL53LMZ_STATUS_OK) {
            printf(">>> [FAIL] vl53lmz_stop_ranging failed! status=0x%02X <<<\r\n", status);
            return status;
        }
    }

    // 2. Set resolution, frequency, and integration time
    status = vl53lmz_set_resolution(&g_vl53lmz_dev, resolution);
    if (status != VL53LMZ_STATUS_OK) {
        printf(">>> [FAIL] vl53lmz_set_resolution failed! status=0x%02X <<<\r\n", status);
        return status;
    }

    status = vl53lmz_set_ranging_frequency_hz(&g_vl53lmz_dev, frequency_hz);
    if (status != VL53LMZ_STATUS_OK) {
        printf(">>> [FAIL] vl53lmz_set_ranging_frequency_hz failed! status=0x%02X <<<\r\n", status);
        return status;
    }

    uint32_t integration_time = (resolution == 16) ? 15 : 20;
    status = vl53lmz_set_integration_time_ms(&g_vl53lmz_dev, integration_time);
    if (status != VL53LMZ_STATUS_OK) {
        printf(">>> [FAIL] vl53lmz_set_integration_time_ms failed! status=0x%02X <<<\r\n", status);
        return status;
    }

    status = vl53lmz_set_ranging_mode(&g_vl53lmz_dev, VL53LMZ_RANGING_MODE_CONTINUOUS);
    if (status != VL53LMZ_STATUS_OK) {
        printf(">>> [FAIL] vl53lmz_set_ranging_mode failed! status=0x%02X <<<\r\n", status);
        return status;
    }

    // 3. Configure CNH Plugin
    status = vl53lmz_cnh_init_config(&g_cnh_config, 0, (int16_t)num_bins, (int16_t)sub_sample);
    if (status != VL53LMZ_STATUS_OK) {
        printf(">>> [FAIL] vl53lmz_cnh_init_config failed! status=0x%02X <<<\r\n", status);
        return status;
    }

    int16_t grid_dim = (resolution == 16) ? 4 : 8;
    status = vl53lmz_cnh_create_agg_map(&g_cnh_config, (int16_t)resolution, 0, 0, 1, 1, grid_dim, grid_dim);
    if (status != VL53LMZ_STATUS_OK) {
        printf(">>> [FAIL] vl53lmz_cnh_create_agg_map failed! status=0x%02X <<<\r\n", status);
        return status;
    }

    status = vl53lmz_cnh_calc_required_memory(&g_cnh_config, &g_cnh_data_size);
    if (status != VL53LMZ_STATUS_OK || g_cnh_data_size > VL53LMZ_CNH_MAX_DATA_BYTES) {
        printf(">>> [FAIL] CNH memory calculation error: %lu bytes <<<\r\n", g_cnh_data_size);
        return VL53LMZ_STATUS_ERROR;
    }
    vl53lmz_cnh_calc_min_max_distance(&g_cnh_config, &g_cnh_min_dist, &g_cnh_max_dist);
    printf("   CNH Memory: %lu bytes (Max: %lu) | Distance Span: %d - %d mm\r\n",
           g_cnh_data_size, VL53LMZ_CNH_MAX_DATA_BYTES, g_cnh_min_dist, g_cnh_max_dist);

    status = vl53lmz_cnh_send_config(&g_vl53lmz_dev, &g_cnh_config);
    if (status != VL53LMZ_STATUS_OK) {
        printf(">>> [FAIL] vl53lmz_cnh_send_config failed! status=0x%02X <<<\r\n", status);
        return status;
    }

    // 4. Build output descriptor with CNH block
    status = vl53lmz_create_output_config(&g_vl53lmz_dev);
    if (status != VL53LMZ_STATUS_OK) {
        printf(">>> [FAIL] vl53lmz_create_output_config failed! status=0x%02X <<<\r\n", status);
        return status;
    }

    union Block_header cnh_data_bh;
    cnh_data_bh.idx = VL53LMZ_CNH_DATA_IDX;
    cnh_data_bh.type = 4;
    cnh_data_bh.size = g_cnh_data_size / 4;
    status = vl53lmz_add_output_block(&g_vl53lmz_dev, cnh_data_bh.bytes);
    if (status != VL53LMZ_STATUS_OK) {
        printf(">>> [FAIL] vl53lmz_add_output_block failed! status=0x%02X <<<\r\n", status);
        return status;
    }

    // 5. Update global profile state
    g_current_resolution = resolution;
    g_cnh_num_bins = num_bins;
    g_cnh_sub_sample = sub_sample;
    g_ranging_freq_hz = frequency_hz;

    // 6. Resume ranging if it was active previously
    if (was_ranging) {
        status = vl53lmz_send_output_config_and_start(&g_vl53lmz_dev);
        if (status == VL53LMZ_STATUS_OK) {
            g_ranging_active = 1;
            printf("[PROFILE] Ranging restarted successfully.\r\n");
        } else {
            printf(">>> [FAIL] Failed to restart ranging! status=0x%02X <<<\r\n", status);
            return status;
        }
    }

    printf("[PROFILE] Reconfiguration complete: %s (%d Zones, %d Bins @ %d Hz)\r\n",
           (resolution == 16) ? "4x4" : "8x8", resolution, num_bins, frequency_hz);
    return VL53LMZ_STATUS_OK;
}

void Set_Sensor_Ranging(uint8_t enable) {
    if (enable && !g_ranging_active) {
        uint8_t status = vl53lmz_send_output_config_and_start(&g_vl53lmz_dev);
        if (status == VL53LMZ_STATUS_OK) {
            g_ranging_active = 1;
            printf("[SENSOR] Ranging resumed.\r\n");
        } else {
            printf("[SENSOR] Resume failed (0x%02X), reinitializing...\r\n", status);
            Init_VL53LMZ_Sensor();
        }
    } else if (!enable && g_ranging_active) {
        uint8_t status = vl53lmz_stop_ranging(&g_vl53lmz_dev);
        g_ranging_active = 0;
        printf("[SENSOR] Ranging paused.\r\n");
        (void)status;
    }
}
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
int main(void)
{

  /* MCU Configuration--------------------------------------------------------*/

  /* MPU Configuration--------------------------------------------------------*/
  MPU_Config();

  /* Reset of all peripherals, Initializes the Flash interface and the Systick. */
  HAL_Init();

  /* Configure the system clock */
  SystemClock_Config();

  /* Configure the peripherals common clocks */
  PeriphCommonClock_Config();

  /* Initialize all configured peripherals */
  MX_GPIO_Init();
  MX_ICACHE_Init();
  MX_SPI1_Init();
  MX_USART1_UART_Init();
  MX_X_CUBE_AI_Init();
  /* USER CODE BEGIN 2 */
  printf("\r\n==============================================\r\n");
  printf("EdgeSense STM32H533 Initializing...\r\n");
  printf("Core Clock (SYSCLK): %lu MHz\r\n", HAL_RCC_GetSysClockFreq() / 1000000);

  // 1. Initialize USB PCD Hardware & Classic ST USB Device Stack
  printf("Starting USB Controller & Classic ST USB Device CDC Stack...\r\n");
  MX_USB_PCD_Init();

  // 2. Connect internal D+ pull-up to host PC
  printf("Connecting USB D+ Pull-Up to PC Host...\r\n");
  HAL_PCD_DevDisconnect(&hpcd_USB_DRD_FS);
  HAL_Delay(100);
  HAL_PCD_DevConnect(&hpcd_USB_DRD_FS);
  HAL_StatusTypeDef pcd_status = HAL_PCD_Start(&hpcd_USB_DRD_FS);
  printf("USB Transceiver Started: %s\r\n", (pcd_status == HAL_OK) ? "SUCCESS" : "FAILED");
  printf("Communication Active: Hardware UART (J5) + USB-C (J4)\r\n");
  printf("==============================================\r\n");

  // 3. Initialize VL53L8CH ULD Driver with CNH and Start Ranging
  Init_VL53LMZ_Sensor();

  // 4. Initialize Asynchronous AT Command Processor
  AT_Cmd_Init();

  /* USER CODE END 2 */

  /* Infinite loop */
  /* USER CODE BEGIN WHILE */
  uint32_t last_paused_tick = HAL_GetTick();
  uint8_t rx_char = 0;

  while (1)
  {
    /* USER CODE END WHILE */

  MX_X_CUBE_AI_Process();
    /* USER CODE BEGIN 3 */
    // 1. Pump non-blocking USB CDC output
    USB_CDC_TxPump();

    // 2. Process UART keyboard input
    if (HAL_UART_Receive(&huart1, &rx_char, 1, 0) == HAL_OK) {
        AT_Cmd_FeedChar((char)rx_char);
    }

    // 3. Process pending AT commands in main thread context (non-blocking)
    AT_Cmd_Process();

    // 4. Sensor data acquisition when VL_INT is LOW (Active-Low Interrupt: Data Ready)
    if (g_ranging_active && HAL_GPIO_ReadPin(VL_INT_GPIO_Port, VL_INT_Pin) == GPIO_PIN_RESET) {
        uint8_t status = vl53lmz_get_ranging_data(&g_vl53lmz_dev, &g_vl53lmz_results);
        if (status == VL53LMZ_STATUS_OK) {
            // Extract the CNH raw histogram block from the transfer buffer
            status = vl53lmz_results_extract_block(&g_vl53lmz_dev, VL53LMZ_CNH_DATA_IDX, 
                                                  (uint8_t *)g_cnh_data_buffer, (uint16_t)g_cnh_data_size);
            if (status == VL53LMZ_STATUS_OK) {
                g_frame_count++;
                uint32_t now = HAL_GetTick();
                if (now != g_last_frame_tick) {
                    g_fps = 1000.0f / (float)(now - g_last_frame_tick);
                }
                g_last_frame_tick = now;

                // Streaming telemetry according to active stream mode
                StreamMode_t sm = Pipeline_GetStreamMode();
                if (sm == STREAM_MODE_RAW || sm == STREAM_MODE_DEBUG) {
                    Print_JSON_Stream(&g_vl53lmz_results, g_frame_count);
                }

                // Real-Time Multi-Capability AI Pipeline (Gesture, Posture, Surface, Smoke)
                Pipeline_FeedFrame(&g_vl53lmz_results, (const uint32_t *)g_cnh_data_buffer, g_cnh_data_size);
            }
        }
    }

    // 5. Heartbeat when paused
    if (!g_ranging_active && (HAL_GetTick() - last_paused_tick >= 5000)) {
        last_paused_tick = HAL_GetTick();
        printf("[PAUSED] Send 'AT+RESUME' to start ranging, 'AT+HELP' for command list.\r\n");
    }
  }
  /* USER CODE END 3 */
}

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
 /* MPU Configuration */

void MPU_Config(void)
{
  MPU_Region_InitTypeDef MPU_InitStruct = {0};
  MPU_Attributes_InitTypeDef MPU_AttributesInit = {0};

  /* Disables the MPU */
  HAL_MPU_Disable();

  /** Initializes and configures the Region 0 and the memory to be protected
  */
  MPU_InitStruct.Enable = MPU_REGION_ENABLE;
  MPU_InitStruct.Number = MPU_REGION_NUMBER0;
  MPU_InitStruct.BaseAddress = 0x08FFF000;
  MPU_InitStruct.LimitAddress = 0x08FFFFFF;
  MPU_InitStruct.AttributesIndex = MPU_ATTRIBUTES_NUMBER0;
  MPU_InitStruct.AccessPermission = MPU_REGION_ALL_RO;
  MPU_InitStruct.DisableExec = MPU_INSTRUCTION_ACCESS_DISABLE;
  MPU_InitStruct.IsShareable = MPU_ACCESS_NOT_SHAREABLE;

  HAL_MPU_ConfigRegion(&MPU_InitStruct);

  /** Initializes and configures the Attribute 0 and the memory to be protected
  */
  MPU_AttributesInit.Number = MPU_ATTRIBUTES_NUMBER0;
  MPU_AttributesInit.Attributes = INNER_OUTER(MPU_NOT_CACHEABLE);

  HAL_MPU_ConfigMemoryAttributes(&MPU_AttributesInit);
  /* Enables the MPU */
  HAL_MPU_Enable(MPU_PRIVILEGED_DEFAULT);

}

/**
  * @brief  This function is executed in case of error occurrence.
  * @param None
  * @retval None
  */
void Error_Handler(void)
{
  /* USER CODE BEGIN Error_Handler_Debug */
  /* User can add his own implementation to report the HAL error return state */
  __disable_irq();
  while (1)
  {
  }
  /* USER CODE END Error_Handler_Debug */
}
#ifdef USE_FULL_ASSERT
/**
  * @brief  Reports the name of the source file and the source line number
  *         where the assert_param error has occurred.
  * @param  file: pointer to the source file name
  * @param  line: assert_param error line source number
  * @retval None
  */
void assert_failed(uint8_t *file, uint32_t line)
{
  /* USER CODE BEGIN 6 */
  /* User can add his own implementation to report the file name and line number,
     ex: printf("Wrong parameters value: file %s on line %d\r\n", file, line) */
  /* USER CODE END 6 */
}
#endif /* USE_FULL_ASSERT */

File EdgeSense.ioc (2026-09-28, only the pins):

Mcu.UserName=STM32H533CEUx
PA10.Signal=USART1_RX
PA11.Signal=USB_DM
PA12.Signal=USB_DP
PA13(JTMS/SWDIO).Signal=DEBUG_JTMS-SWDIO
PA14(JTCK/SWCLK).Signal=DEBUG_JTCK-SWCLK
PA4.GPIO_Label=VL_NCS
PA4.Signal=GPIO_Output
PA5.Signal=SPI1_SCK
PA6.Signal=SPI1_MISO
PA7.Signal=SPI1_MOSI
PA9.Signal=USART1_TX
PB0.GPIO_Label=VL_INT
PB0.Signal=GPIO_Input
PB1.GPIO_Label=VL_XSHUT
PB1.Signal=GPIO_Output
PB2.GPIO_Label=VL_SYNC
PB2.Signal=GPIO_Output
PC14-OSC32_IN(OSC32_IN).Signal=RCC_OSC32_IN
PC15-OSC32_OUT(OSC32_OUT).Signal=RCC_OSC32_OUT
PH0-OSC_IN(PH0).Signal=RCC_OSC_IN
PH1-OSC_OUT(PH1).Signal=RCC_OSC_OUT

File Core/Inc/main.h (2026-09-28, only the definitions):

#define VL_NCS_Pin GPIO_PIN_4
#define VL_NCS_GPIO_Port GPIOA
#define VL_INT_Pin GPIO_PIN_0
#define VL_INT_GPIO_Port GPIOB
#define VL_XSHUT_Pin GPIO_PIN_1
#define VL_XSHUT_GPIO_Port GPIOB
#define VL_SYNC_Pin GPIO_PIN_2
#define VL_SYNC_GPIO_Port GPIOB

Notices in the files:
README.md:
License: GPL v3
